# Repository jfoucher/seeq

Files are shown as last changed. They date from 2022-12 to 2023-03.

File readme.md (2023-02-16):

## SEEQ a MIDI and CV/gate sequencer

3D View top

3D View bottom

### What is it?

This project is a simple sequencer I designed and built. I started a project to build an analog synthesizer, but I did not have anything that would be able to output the necessary CV signals, so I decided to build one.

And then I added MIDI input and output to be able to interface with other things.

I designed it around a Raspberry Pi Pico because it is cheap, easy to use and fast.

### Using the sequencer

You have 16 steps, with one key and one LED for each step. Turning the knob in one direction makes the tempo faster, and in the other direction makes it slower.

If you press a key while turning the knob, this changes the pitch of that step.

If you turn the knob while pressing on it, it changes the number of steps in the sequence.

If you turn the knob while pressing on it while having a step switch pressed, it changes the velocity of that (this only has an effect for the MIDI output)

If you press the knob quickly once, it pauses or restarts playback.

If you press the knob twice, you enter recording mode. This then takes MIDI input (over USB or the midi in plug) and assigns the note you play to the current step and advances to the next step.

## Building it

Instructions will come soon

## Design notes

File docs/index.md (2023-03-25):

---
layout: page
title: A simple sequencer with MIDI and CV/gate output
---

[Schematic](https://6px.eu/seeq/fabrication/seeq-schematic.pdf)

[Gerber files](https://6px.eu/seeq/fabrication/seeq-zip.zip)

[Download BOM](https://6px.eu/seeq/fabrication/seeq-bom.csv)

[View BOM](https://6px.eu/seeq/fabrication/seeq-bom.html)

3D View top

3D View bottom

This project is a simple sequencer I designed and built. I started a project to build an analog synthesizer, but I did not have anything that would be able to output the necessary CV signals, so I decided to build one.

And then I added MIDI input and output to be able to interface with other things.

The way it works is fairly simple.

You have 16 steps, with one key and one LED for each step. Turning the knob in one direction makes the tempo faster, and in the other direction makes it slower.

If you press a key while turning the knob, this changes the pitch of that step.

If you turn the knob while pressing on it, it changes the number of steps in the sequence.

If you turn the knob while pressing on it while having a step switch pressed, it changes the velocity of that (this only has an effect for the MIDI output)

If you press the knob quickly once, it pauses or restarts playback.

If you press the knob twice, you enter recording mode. This then takes MIDI input (over USB or the midi in plug) and assigns the note you play to the current step and advances to the next step.

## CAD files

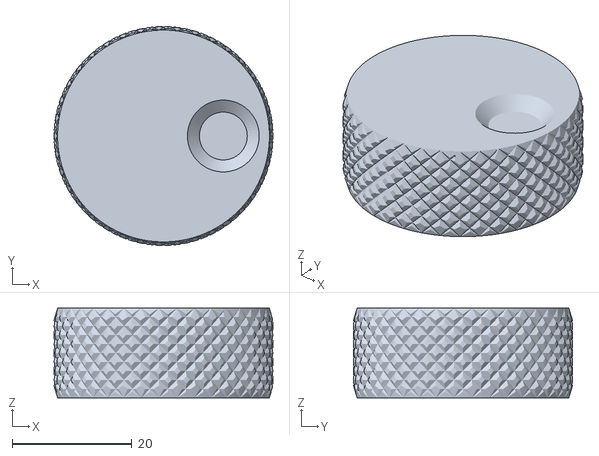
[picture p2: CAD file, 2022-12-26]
case/dist/knob.stl
36.6 x 36.6 x 15.0

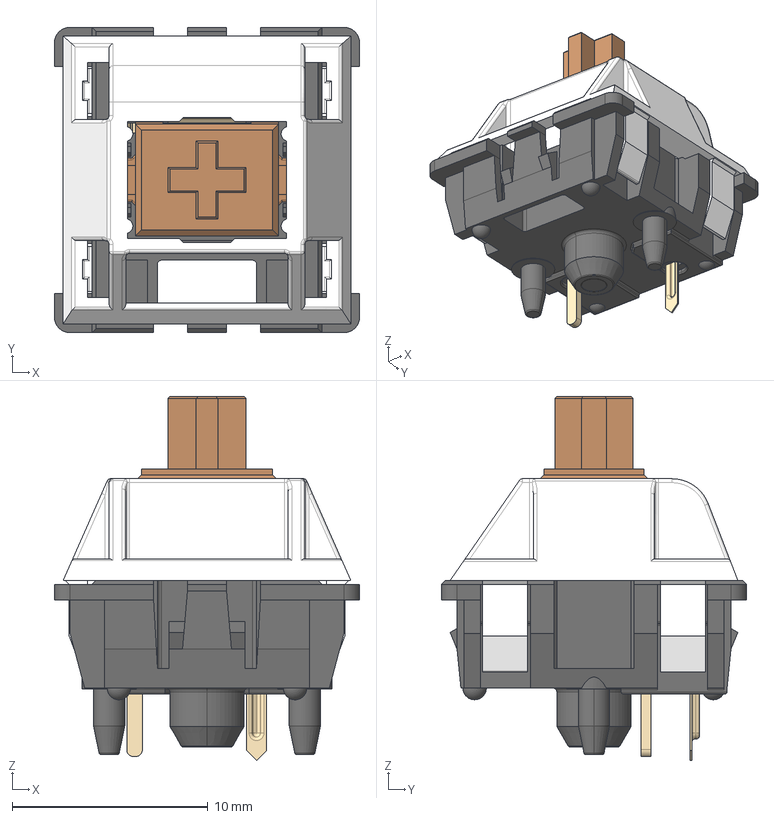
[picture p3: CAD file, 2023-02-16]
hardware/mod/3D/SW_Cherry_MX_PCB.stp
15.6 x 15.6 x 18.6 mm

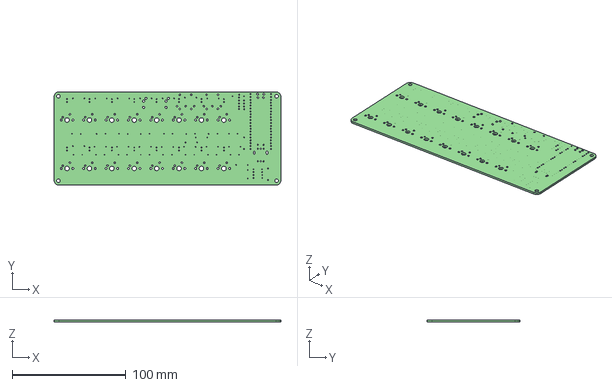
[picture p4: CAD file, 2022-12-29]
hardware/seeq.step
199.5 x 82.0 x 1.60 mm

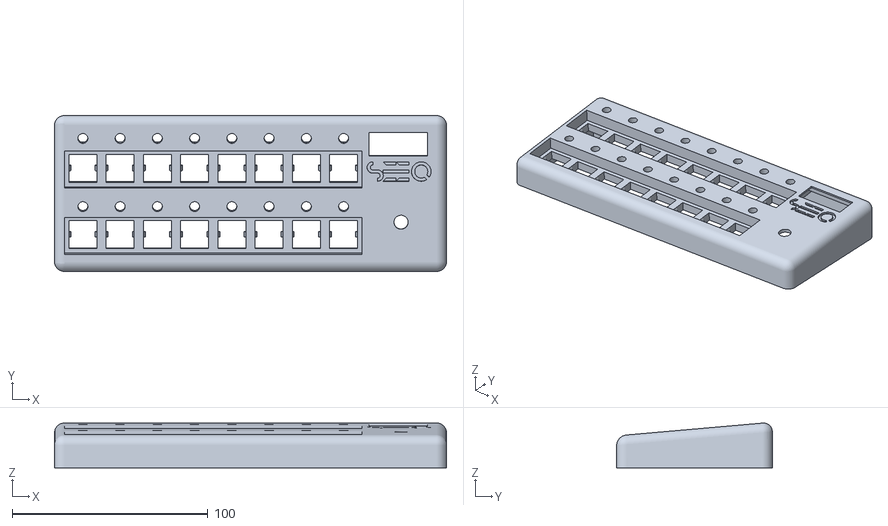
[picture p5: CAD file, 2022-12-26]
case/dist/top.stl
200.5 x 79.7 x 23.0

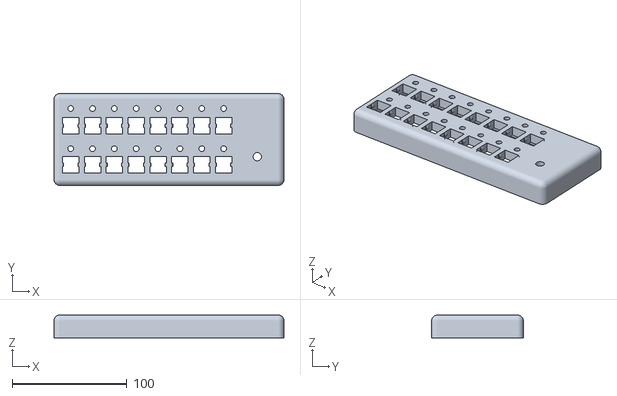
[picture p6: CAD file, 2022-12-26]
case/dist/output.stl
200.5 x 80.0 x 20.0

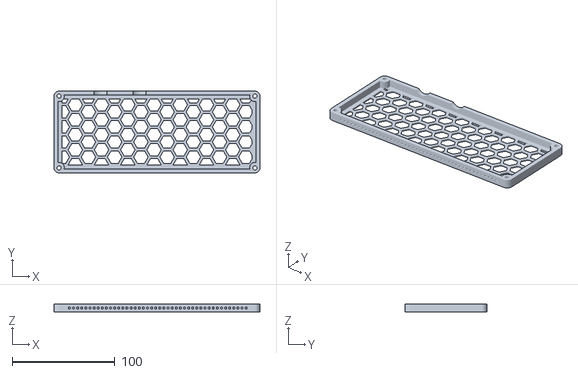
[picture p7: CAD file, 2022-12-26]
case/dist/bottom.stl
200.5 x 79.7 x 8.00

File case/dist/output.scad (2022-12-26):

/*
 * knurledFinishLib.scad
 * 
 * Written by aubenc @ Thingiverse
 *
 * This script is licensed under the Public Domain license.
 *
 * http://www.thingiverse.com/thing:9095
 *
 * Usage:
 *
 *    knurled_cyl( Knurled cylinder height,
 *                 Knurled cylinder outer diameter,
 *                 Knurl polyhedron width,
 *                 Knurl polyhedron height,
 *                 Knurl polyhedron depth,
 *                 Cylinder ends smoothed height,
 *                 Knurled surface smoothing amount );
 */
module knurled_cyl(chg, cod, cwd, csh, cdp, fsh, smt)
{
    cord=(cod+cdp+cdp*smt/100)/2;
    cird=cord-cdp;
    cfn=round(2*cird*PI/cwd);
    clf=360/cfn;
    crn=ceil(chg/csh);

    intersection()
    {
        shape(fsh, cird, cord-cdp*smt/100, cfn*4, chg);

        translate([0,0,-(crn*csh-chg)/2])
          knurled_finish(cord, cird, clf, csh, cfn, crn);
    }
}

module shape(hsh, ird, ord, fn4, hg)
{
        union()
        {
            cylinder(h=hsh, r1=ird, r2=ord, $fn=fn4, center=false);

            translate([0,0,hsh-0.002])
              cylinder(h=hg-2*hsh+0.004, r=ord, $fn=fn4, center=false);

            translate([0,0,hg-hsh])
              cylinder(h=hsh, r1=ord, r2=ird, $fn=fn4, center=false);
        }

}

module knurled_finish(ord, ird, lf, sh, fn, rn)
{
    for(j=[0:rn-1])
    
    {
      h0=sh*j;
      h1=sh*(j+1/2);
      h2=sh*(j+1);
        for(i=[0:fn-1])
        
        {
          lf0=lf*i;
        lf1=lf*(i+1/2);
        lf2=lf*(i+1);
            polyhedron(
                points=[
                     [ 0,0,h0],
                     [ ord*cos(lf0), ord*sin(lf0), h0],
                     [ ird*cos(lf1), ird*sin(lf1), h0],
                     [ ord*cos(lf2), ord*sin(lf2), h0],

                     [ ird*cos(lf0), ird*sin(lf0), h1],
                     [ ord*cos(lf1), ord*sin(lf1), h1],
                     [ ird*cos(lf2), ird*sin(lf2), h1],

                     [ 0,0,h2],
                     [ ord*cos(lf0), ord*sin(lf0), h2],
                     [ ird*cos(lf1), ird*sin(lf1), h2],
                     [ ord*cos(lf2), ord*sin(lf2), h2]
                    ],
                faces=[
                     [0,1,2],[2,3,0],
                     [1,0,4],[4,0,7],[7,8,4],
                     [8,7,9],[10,9,7],
                     [10,7,6],[6,7,0],[3,6,0],
                     [2,1,4],[3,2,6],[10,6,9],[8,9,4],
                     [4,5,2],[2,5,6],[6,5,9],[9,5,4]
                    ],
                convexity=5);
         }
    }
}
$fn = 64;
union()
{
  difference()
  {
    union()
    {
      rotate(a = [5, 0, 0], v = undef)
      {
        union()
        {
          translate(v = [0, -22, -7])
          {
            union()
            {
              translate(v = [-85.72500000000001, 0, 16])
              {
                union()
                {
                  union()
                  {
                    translate(v = [0, 7.95, 2])
                    {
                      cube(size = [17.4, 1.5, 4], center = true);
                    }
                    translate(v = [7.95, 0, 2])
                    {
                      cube(size = [1.5, 17.4, 4], center = true);
                    }
                    hull()
                    {
                      translate(v = [7.2, 0, 1])
                      {
                        rotate(a = [90, 0, 0], v = undef)
                        {
                          cylinder(h = 2.75, r = 1, center = true);
                        }
                      }
                      translate(v = [7.95, 0, 2])
                      {
                        cube(size = [1.5, 2.75, 4], center = true);
                      }
                    }
                  }
                  mirror(v = [0, 1, 0])
                  {
                    mirror(v = [1, 0, 0])
                    {
                      union()
                      {
                        translate(v = [0, 7.95, 2])
                        {
                          cube(size = [17.4, 1.5, 4], center = true);
                        }
                        translate(v = [7.95, 0, 2])
                        {
                          cube(size = [1.5, 17.4, 4], center = true);
                        }
                        hull()
                        {
                          translate(v = [7.2, 0, 1])
                          {
                            rotate(a = [90, 0, 0], v = undef)
                            {
                              cylinder(h = 2.75, r = 1, center = true);
                            }
                          }
                          translate(v = [7.95, 0, 2])
                          {
                            cube(size = [1.5, 2.75, 4], center = true);
                          }
                        }
                      }
                    }
                  }
                }
              }
              translate(v = [-66.67500000000001, 0, 16])
              {
                union()
                {
                  union()
                  {
                    translate(v = [0, 7.95, 2])
                    {
                      cube(size = [17.4, 1.5, 4], center = true);
                    }
                    translate(v = [7.95, 0, 2])
                    {
                      cube(size = [1.5, 17.4, 4], center = true);
                    }
                    hull()
                    {
                      translate(v = [7.2, 0, 1])
                      {
                        rotate(a = [90, 0, 0], v = undef)
                        {
                          cylinder(h = 2.75, r = 1, center = true);
                        }
                      }
                      translate(v = [7.95, 0, 2])
                      {
                        cube(size = [1.5, 2.75, 4], center = true);
                      }
                    }
                  }
                  mirror(v = [0, 1, 0])
                  {
                    mirror(v = [1, 0, 0])
                    {
                      union()
                      {
                        translate(v = [0, 7.95, 2])
                        {
                          cube(size = [17.4, 1.5, 4], center = true);
                        }
                        translate(v = [7.95, 0, 2])
                        {
                          cube(size = [1.5, 17.4, 4], center = true);
                        }
                        hull()
                        {
                          translate(v = [7.2, 0, 1])
                          {
                            rotate(a = [90, 0, 0], v = undef)
                            {
                              cylinder(h = 2.75, r = 1, center = true);
                            }
                          }
                          translate(v = [7.95, 0, 2])
                          {
                            cube(size = [1.5, 2.75, 4], center = true);
                          }
                        }
                      }
                    }
                  }
                }
              }
              translate(v = [-47.62500000000001, 0, 16])
              {
                union()
                {
                  union()
                  {
                    translate(v = [0, 7.95, 2])
                    {
                      cube(size = [17.4, 1.5, 4], center = true);
                    }
                    translate(v = [7.95, 0, 2])
                    {
                      cube(size = [1.5, 17.4, 4], center = true);
                    }
                    hull()
                    {
                      translate(v = [7.2, 0, 1])
                      {
                        rotate(a = [90, 0, 0], v = undef)
                        {
                          cylinder(h = 2.75, r = 1, center = true);
                        }
                      }
                      translate(v = [7.95, 0, 2])
                      {
                        cube(size = [1.5, 2.75, 4], center = true);
                      }
                    }
                  }
                  mirror(v = [0, 1, 0])
                  {
                    mirror(v = [1, 0, 0])
                    {
                      union()
                      {
                        translate(v = [0, 7.95, 2])
                        {
                          cube(size = [17.4, 1.5, 4], center = true);
                        }
                        translate(v = [7.95, 0, 2])
                        {
                          cube(size = [1.5, 17.4, 4], center = true);
                        }
                        hull()
                        {
                          translate(v = [7.2, 0, 1])
                          {
                            rotate(a = [90, 0, 0], v = undef)
                            {
                              cylinder(h = 2.75, r = 1, center = true);
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

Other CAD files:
hardware/seeq.stl

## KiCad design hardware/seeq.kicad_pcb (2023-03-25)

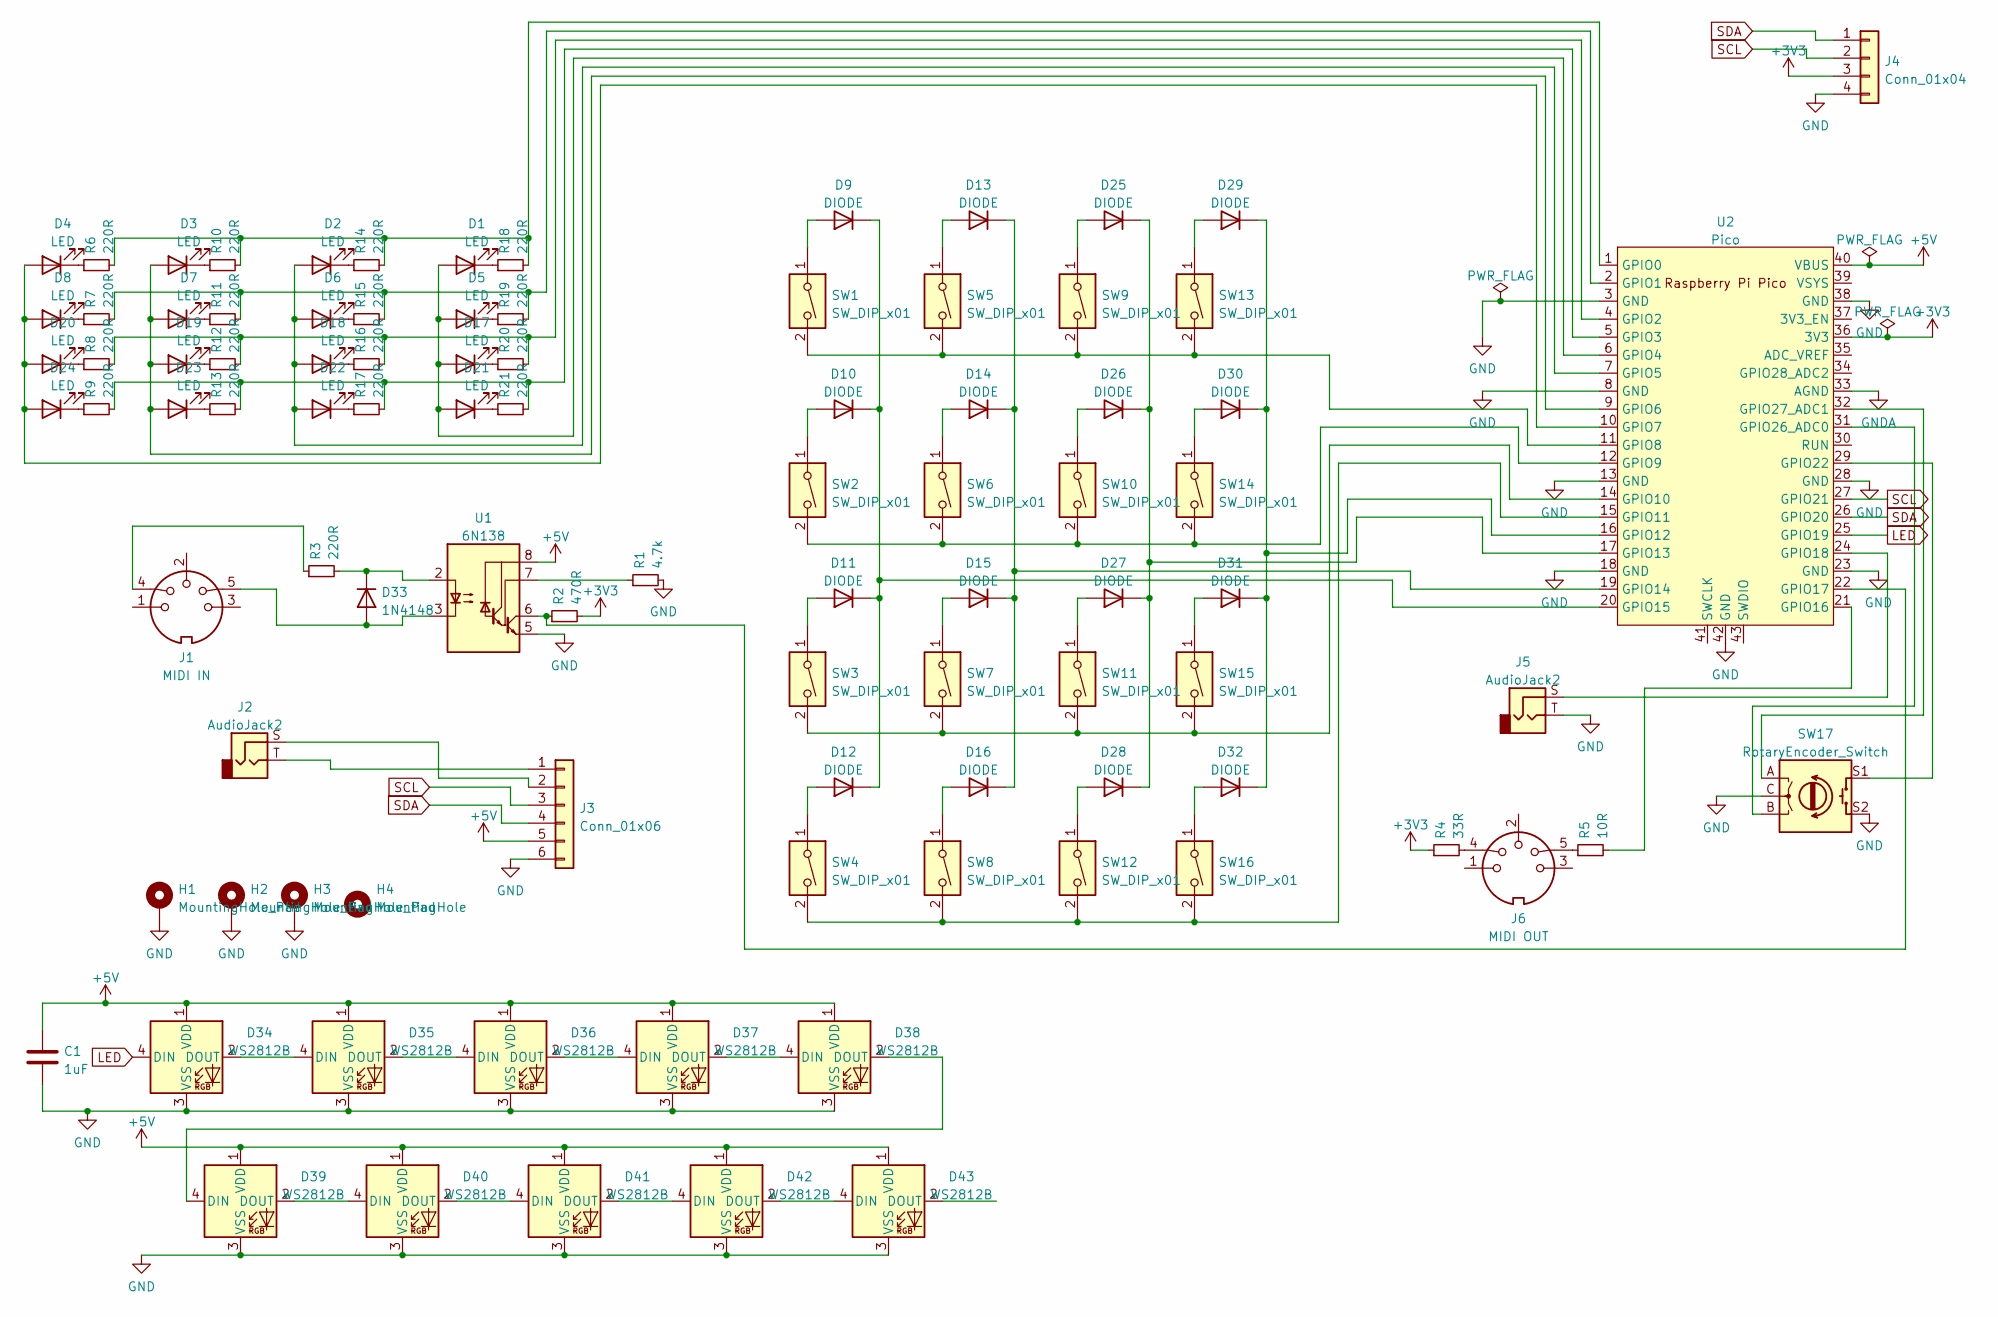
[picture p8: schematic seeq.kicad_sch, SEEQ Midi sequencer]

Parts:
C1: 1uF; C_Disc_D5.0mm_W2.5mm_P5.00mm
D1, D2, D3, D4, D5, D6, D7, D8, D17, D18, D19, D20, D21, D22, D23, D24: LED; LED_D5.0mm
D9, D10, D11, D12, D13, D14, D15, D16, D25, D26, D27, D28, D29, D30, D31, D32: DIODE; D_DO-35_SOD27_P7.62mm_Horizontal
D33: 1N4148; D_DO-35_SOD27_P7.62mm_Horizontal
D34, D35, D36, D37, D38, D39, D40, D41, D42, D43: WS2812B; LED_WS2812B_PLCC4_5.0x5.0mm_P3.2mm
H1, H2, H3: MountingHole_Pad; MountingHole_3.2mm_M3_Pad
H4: MountingHole; MountingHole_3.2mm_M3
J1: MIDI IN; din-5
J2, J5: AudioJack2; TRRS-PJ-320A-no-Fmask
J3: Conn_01x06; PinSocket_1x06_P2.54mm_Vertical
J4: Conn_01x04; PinSocket_1x04_P2.54mm_Vertical
J6: MIDI OUT; din-5
R1: 4.7k; R_Axial_DIN0207_L6.3mm_D2.5mm_P10.16mm_Horizontal
R2: 470R; R_Axial_DIN0207_L6.3mm_D2.5mm_P10.16mm_Horizontal
R3, R6, R7, R8, R9, R10, R11, R12, R13, R14, R15, R16, R17, R18, R19, R20, R21: 220R; R_Axial_DIN0207_L6.3mm_D2.5mm_P10.16mm_Horizontal
R4: 33R; R_Axial_DIN0207_L6.3mm_D2.5mm_P10.16mm_Horizontal
R5: 10R; R_Axial_DIN0207_L6.3mm_D2.5mm_P10.16mm_Horizontal
SW1, SW2, SW3, SW4, SW5, SW6, SW7, SW8, SW9, SW10, SW11, SW12, SW13, SW14, SW15, SW16: SW_DIP_x01; SW_Cherry_MX_PCB_1.00u
SW17: RotaryEncoder_Switch; RotaryEncoder_Alps_EC11E-Switch_Vertical_H20mm
U1: 6N138; DIP-8_W7.62mm
U2: Pico; RPi_Pico_SMD_TH

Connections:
+3V3: J4.3, R2.2, R4.1, U2.36 (3V3)
+5V: C1.1, D34.1 (VDD), D35.1 (VDD), D36.1 (VDD), D37.1 (VDD), D38.1 (VDD), D39.1 (VDD), D40.1 (VDD), D41.1 (VDD), D42.1 (VDD), D43.1 (VDD), J3.5, U1.8 (VCC), U2.40 (VBUS)
GND: C1.2, D34.3 (VSS), D35.3 (VSS), D36.3 (VSS), D37.3 (VSS), D38.3 (VSS), D39.3 (VSS), D40.3 (VSS), D41.3 (VSS), D42.3 (VSS), D43.3 (VSS), H1.1, H2.1, H3.1, J3.6, J4.4, J5.T, R1.2, SW17.C, SW17.S2, U1.5 (GND), U2.3 (GND), U2.8 (GND), U2.13 (GND), U2.18 (GND), U2.23 (GND), U2.28 (GND), U2.38 (GND), U2.42 (GND)
GNDA: U2.33 (AGND)
LED: D34.4 (DIN), U2.25 (GPIO19)
unnamed: D1.1 (K), R18.1
unnamed: D1.2 (A), D5.2 (A), D17.2 (A), D21.2 (A), U2.6 (GPIO4)
unnamed: D2.1 (K), R14.1
unnamed: D3.1 (K), R10.1
unnamed: D4.1 (K), R6.1
unnamed: D5.1 (K), R19.1
unnamed: D6.1 (K), R15.1
unnamed: D7.1 (K), R11.1
unnamed: D8.1 (K), R7.1
unnamed: D9.2 (A), SW1.1
unnamed: D9.1 (K), D10.1 (K), D11.1 (K), D12.1 (K), U2.20 (GPIO15)
unnamed: D10.2 (A), SW2.1
unnamed: D11.2 (A), SW3.1
unnamed: D12.2 (A), SW4.1
unnamed: D13.1 (K), D14.1 (K), D15.1 (K), D16.1 (K), U2.19 (GPIO14)
unnamed: D13.2 (A), SW5.1
unnamed: D14.2 (A), SW6.1
unnamed: D15.2 (A), SW7.1
unnamed: D16.2 (A), SW8.1
unnamed: D17.1 (K), R20.1
unnamed: D18.1 (K), R16.1
unnamed: D2.2 (A), D6.2 (A), D18.2 (A), D22.2 (A), U2.7 (GPIO5)
unnamed: D19.1 (K), R12.1
unnamed: D3.2 (A), D7.2 (A), D19.2 (A), D23.2 (A), U2.9 (GPIO6)
unnamed: D20.1 (K), R8.1
unnamed: D4.2 (A), D8.2 (A), D20.2 (A), D24.2 (A), U2.10 (GPIO7)
unnamed: D21.1 (K), R21.1
unnamed: D22.1 (K), R17.1
unnamed: D23.1 (K), R13.1
unnamed: D24.1 (K), R9.1
unnamed: D25.1 (K), D26.1 (K), D27.1 (K), D28.1 (K), U2.17 (GPIO13)
unnamed: D25.2 (A), SW9.1
unnamed: D26.2 (A), SW10.1
unnamed: D27.2 (A), SW11.1
unnamed: D28.2 (A), SW12.1
unnamed: D29.1 (K), D30.1 (K), D31.1 (K), D32.1 (K), U2.16 (GPIO12)
unnamed: D29.2 (A), SW13.1
unnamed: D30.2 (A), SW14.1
unnamed: D31.2 (A), SW15.1
unnamed: D32.2 (A), SW16.1
unnamed: D33.1 (K), R3.2, U1.2 (C1)
unnamed: D33.2 (A), J1.5, U1.3 (C2)
unnamed: D34.2 (DOUT), D35.4 (DIN)
unnamed: D35.2 (DOUT), D36.4 (DIN)
unnamed: D36.2 (DOUT), D37.4 (DIN)
unnamed: D37.2 (DOUT), D38.4 (DIN)
unnamed: D38.2 (DOUT), D39.4 (DIN)
unnamed: D39.2 (DOUT), D40.4 (DIN)
unnamed: D40.2 (DOUT), D41.4 (DIN)
unnamed: D41.2 (DOUT), D42.4 (DIN)
unnamed: D42.2 (DOUT), D43.4 (DIN)
unnamed: J1.4, R3.1
unnamed: J2.S, J3.2
unnamed: J2.T, J3.1
unnamed: J5.S, U2.24 (GPIO18)
unnamed: J6.4, R4.2
unnamed: J6.5, R5.1
unnamed: R1.1, U1.7 (VO1)
unnamed: R2.1, U1.6 (VO2), U2.22 (GPIO17)
unnamed: R5.2, U2.21 (GPIO16)
unnamed: R6.2, R10.2, R14.2, R18.2, U2.1 (GPIO0)
unnamed: R7.2, R11.2, R15.2, R19.2, U2.2 (GPIO1)
unnamed: R8.2, R12.2, R16.2, R20.2, U2.4 (GPIO2)
unnamed: R9.2, R13.2, R17.2, R21.2, U2.5 (GPIO3)
unnamed: SW1.2, SW5.2, SW9.2, SW13.2, U2.11 (GPIO8)
unnamed: SW2.2, SW6.2, SW10.2, SW14.2, U2.12 (GPIO9)
unnamed: SW3.2, SW7.2, SW11.2, SW15.2, U2.14 (GPIO10)
unnamed: SW4.2, SW8.2, SW12.2, SW16.2, U2.15 (GPIO11)
unnamed: SW17.A, U2.32 (GPIO27_ADC1)
unnamed: SW17.B, U2.31 (GPIO26_ADC0)
unnamed: SW17.S1, U2.29 (GPIO22)
SCL: J3.3, J4.2, U2.27 (GPIO21)
SDA: J3.4, J4.1, U2.26 (GPIO20)

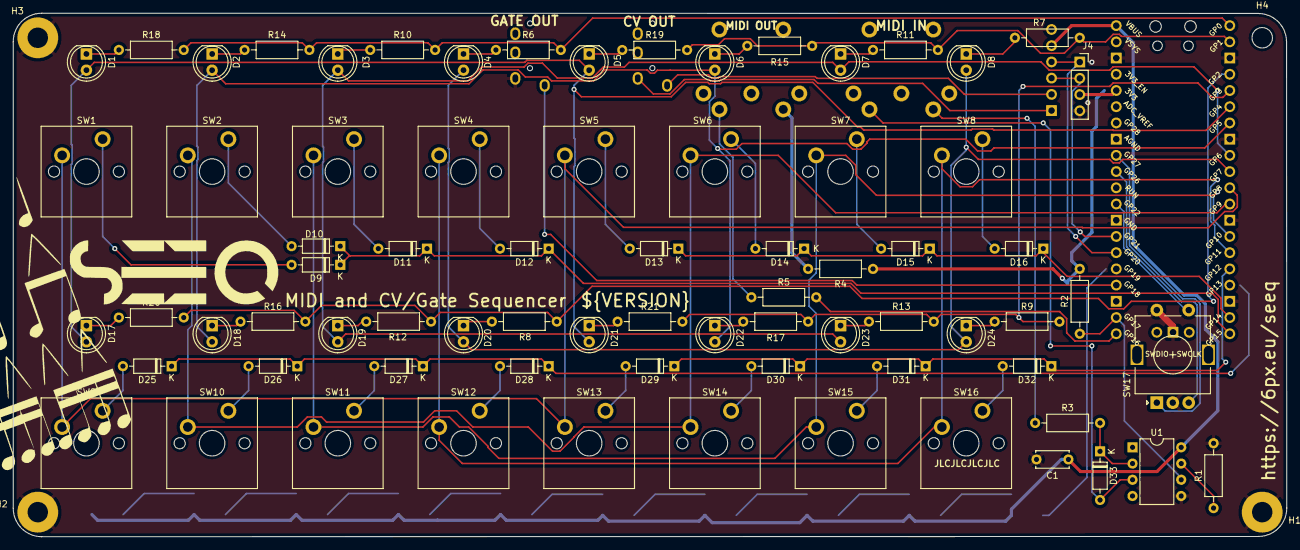
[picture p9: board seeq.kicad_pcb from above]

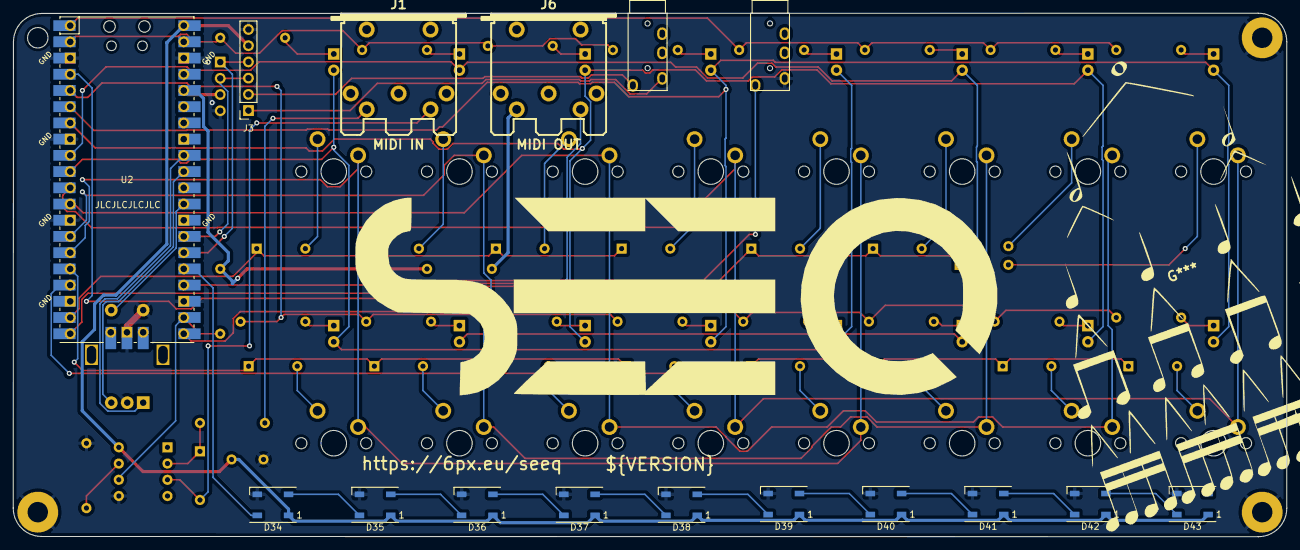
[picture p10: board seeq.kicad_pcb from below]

Board: 2 copper layers, 199.5 x 82.0 mm, 94 parts (16 on the bottom side), 77 nets.

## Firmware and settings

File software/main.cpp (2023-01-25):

/* 
 * The MIT License (MIT)
 *
 * Copyright (c) 2022 Jonathan Foucher - Six Pixels
 *
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
 */

#include <stdlib.h>
#include <stdio.h>
#include <string.h>
#include <stdarg.h>

#include "pico/stdlib.h"
#include "pico/time.h"
#include "pico/sync.h"
#include "hardware/clocks.h"
#include "hardware/vreg.h"
#include "hardware/flash.h"
#include "pico/multicore.h"
#include "pico/util/queue.h"
#include "lib/encoder/encoder.hpp"
#include "lib/OLED/OLED.h"
#include "lib/OLED/font/Cherry_Cream_Soda_Regular_16.h"
#include "lib/OLED/font/Dialog_bold_16.h"

#include "pico/binary_info.h"


#include "lib/picoLED/PicoLed.hpp"

#include "bsp/board.h"
#include "tusb.h"

#include "lib/midi/midi.h"
#include "lib/keypad/keypad.h"

#include "lib/midi/midi.c"
#include "lib/mcp4725/mcp4725.h"
#include "lib/mcp4725/mcp4725.c"
#include "lib/encoder_button/encoder_button.h"
#include "lib/encoder_button/encoder_button.c"
#include "lib/midi_uart_lib/midi_uart_lib.h"

#define MIDI_UART_NUM 1
#define CABLE_NUM 0 // MIDI jack associated with USB endpoint
#define CHANNEL 0 // 0 for channel 1
#define ENCODER_PIN_A 27
#define ENCODER_PIN_B 26

#define FLASH_TARGET_OFFSET (512 * 1024)

 
const uint8_t *flash_target_contents = (const uint8_t *) (XIP_BASE + FLASH_TARGET_OFFSET);

const uint MIDI_UART_TX_GPIO = 16;
const uint MIDI_UART_RX_GPIO = 17;

static void *midi_uart_instance;

void println(const char * format, ... );
void print(const char * format, ... );

void __time_critical_func(core1_func)();
void save_data_task(void);
static semaphore_t video_initted;

uint8_t midi_message[4];
int midi_message_index = 0;

queue_t queue;
queue_t note_queue;
queue_t cv_note_queue;

uint8_t sequence[16] = {74,78,81,86,90,93,98,102,57,61,66,69,73,78,81,85};
uint8_t active[16] = {true, true, true, true,true, true, true, true,true, true, true, true,true, true, true, true};
uint8_t velocity[16] = {127, 127, 127, 127,127, 127, 127, 127,127, 127, 127, 127,127, 127, 127, 127};
int8_t pressed_key = -1;
uint8_t first_step = 0;
uint8_t last_step = 15;
uint8_t new_last_step = 15;
uint8_t current_led = 0;
uint8_t previous_led = 20;
uint8_t play_step = 0;
uint8_t led_row_pins[4] = {0,1,2,3};
uint8_t led_col_pins[4] = {4,5,6,7};

uint16_t tempo = 120;
uint16_t old_tempo = 0;


int note_display = -1;
int old_note_display = 0;
uint16_t note_message = 0;
uint8_t cv_note_message = 0;
uint8_t new_cv_note = 0;

absolute_time_t t;
absolute_time_t last_play_time;
absolute_time_t last_off_time;
absolute_time_t last_keypad_time;
absolute_time_t last_save_time;
absolute_time_t last_manual_save_time;
absolute_time_t last_manual_play_time;
absolute_time_t last_tapped_time;
bool playing = true;
bool recording = false;
bool handled_key_and_encoder_pressed = false;
bool changed_enc_count_on_press = false;

struct SeeqData {
  uint16_t header;
  uint16_t tempo;
  uint8_t first_step;
  uint8_t last_step;
  uint8_t sequence[16];
  uint8_t active[16];
  uint8_t velocity[16];
};

// Keypad pins

uint8_t row_pins[] = {8,9,10,11};
uint8_t col_pins[] = {15,14,13,12};



void init_leds() {
    for(int i = 0; i<4;i++) {
        uint8_t p = led_row_pins[i];

        gpio_init(p);
        gpio_set_dir(p, GPIO_OUT);
        gpio_put(p, 1);
    }
    for(int i = 0; i<4;i++) {
        uint8_t p = led_col_pins[i];

        gpio_init(p);
        gpio_set_dir(p, GPIO_OUT);
        gpio_put(p, 0);
    }
}

int cv_notes[] = {0, 68, 136, 204, 273, 341, 409, 477, 546, 614, 682, 750, 819, 887, 955, 1024, 1092, 1160, 1228, 1297, 1365, 1433, 1501, 1570, 1638, 1706, 1774, 1843, 1911, 1979, 2048, 2116, 2184, 2252, 2321, 2389, 2457, 2525, 2594, 2662, 2730, 2798, 2867, 2935, 3003, 3072, 3140, 3208, 3276, 3345, 3413, 3481, 3549, 3618, 3686, 3754, 3822, 3891, 3959, 4027, 4096}; 

int midi_to_cv(uint8_t midi_note) {
  // Only return something for octaves from 0 to 5
  if (midi_note < 36 || midi_note > 96 ) {
    return 0;
  }

  return cv_notes[midi_note - 36];
}


SeeqData seeqData;

bool saveData() {
    seeqData.tempo = tempo;
    seeqData.header = 0x55AA;
    for (int i = 0; i< 16; i++) {
      seeqData.sequence[i] = sequence[i];
      seeqData.active[i] = active[i];
      seeqData.velocity[i] = velocity[i];
    }
    seeqData.last_step = last_step;
    seeqData.first_step = first_step;

    uint8_t* dataAsBytes = (uint8_t*) &seeqData;
    int dataSize = sizeof(seeqData);
    
    int writeSize = (dataSize / FLASH_PAGE_SIZE) + 1; // how many flash pages we're gonna need to write
    int sectorCount = ((writeSize * FLASH_PAGE_SIZE) / FLASH_SECTOR_SIZE) + 1; // how many flash sectors we're gonna need to erase
    uint32_t interrupts = save_and_disable_interrupts();
    flash_range_erase(FLASH_TARGET_OFFSET, FLASH_SECTOR_SIZE * sectorCount);
    flash_range_program(FLASH_TARGET_OFFSET, dataAsBytes, FLASH_PAGE_SIZE * writeSize);
    restore_interrupts(interrupts);

    for (int i = 0; i < dataSize; ++i) {
        if (dataAsBytes[i] != flash_target_contents[i])
            return false;
    }
    
    return true;
}

void readData() {
    memcpy(&seeqData, flash_target_contents, sizeof(seeqData));
    if (seeqData.header != 0x55AA) {
      return;
    }
    if (seeqData.tempo > 0 && seeqData.tempo <= 5000) {
      tempo = seeqData.tempo;
    }
    if (seeqData.last_step >= 0 && seeqData.last_step <= 15) {
      last_step = (uint8_t)seeqData.last_step;
      new_last_step = last_step;
    }

    if (seeqData.first_step >= 0 && seeqData.first_step <= 15) {
      first_step = (uint8_t)seeqData.first_step;
    }

    for (int i=0; i < 16; i++) {
      if (seeqData.sequence[i] <= 0x7F) {
        sequence[i] = seeqData.sequence[i];
      }
      if (seeqData.active[i] <= 0x7F) {
        active[i] = (bool)seeqData.active[i];
      }

      if (seeqData.velocity[i] <= 0x7F) {
        velocity[i] = (uint8_t)seeqData.velocity[i];
      }
    }
}

void led_display(uint8_t led) {
    if (led == previous_led) {
        return ;
    }
    previous_led = led;
    //turn off all leds
    for(int i = 0; i<4;i++) {
        uint8_t p = led_row_pins[i];
        gpio_put(p, 1);
    }
    for(int i = 0; i<4;i++) {
        uint8_t p = led_col_pins[i];
        gpio_put(p, 0);
    }
    if (led < 16 && led >= 0) {
        uint8_t row = led / 4;
        uint8_t col = led % 4;
        gpio_put(led_row_pins[row], 0);
        gpio_put(led_col_pins[col], 1);
    }
}

const char * notes[] = {
    "C", "C#", "D", "D#", "E", "F", "F#", "G", "G#", "A", "A#", "B"
};


void note_text(char * note_str, uint8_t midi_note) {
  int n = ((int)midi_note) - 24;
  int octave = n / 12;
  if (n < 0) {
    octave = -octave;
  }
  const char * note = notes[midi_note%12];

  sprintf(note_str, "%s%i", note, octave);
}

void __time_critical_func(core1_func)() {    
      // SCL, SDA, Width, Height, Frequency, I2C Port
    OLED oled(21, 20, 128, 32, 300000, false, i2c0);

    // Draw two circles
    oled.drawFilledCircle(100, 4, 4);

    // Print custom font string
    oled.setFont(&Dialog_bold_16);
    uint8_t string2[] = "SEEQ";
    oled.print(60, 5, string2);
    oled.drawFilledRectangle(120, 10, 8, 24);
    // Draw a line
    oled.drawFastHLine(0, 31, 128);
    oled.drawFastHLine(0, 0, 128);
    oled.show();
    
    sleep_ms(500);

    sem_release(&video_initted);
    // Turn scroll ON
    // oled.setScrollDir(true);
    // oled.isScroll(true);
    while (true) {
        tight_loop_contents();
        while (queue_try_remove(&cv_note_queue, &new_cv_note)){
            mcp4725_set(i2c0, MCP4725_ADDR0, midi_to_cv(new_cv_note));
        }

        uint16_t new_tempo = old_tempo;
        while (queue_try_remove(&queue, &new_tempo)){}
        int new_note_display = old_note_display;

        while (queue_try_remove(&note_queue, &new_note_display)){}

        bool clear = old_note_display != new_note_display || old_tempo != new_tempo;

        if (clear) {
          oled.clear();

          char intStr[4];
          sprintf(intStr, "%d",  new_tempo);
          oled.print(0, 0, (uint8_t *)intStr);
          old_tempo = new_tempo;

          char str[4];
          uint8_t note = (new_note_display & 0xFF);
          if (note >= 0 && note <= 0x7F) {
            note_text(str, note);
            //println("note text %s", str);
            
          } else {
            sprintf(str, "%s",  "  - ");
          }

          oled.print(64, 0, (uint8_t *)str);
          old_note_display = new_note_display;
          uint8_t vh = (uint8_t)(new_note_display >> 8) / 4;
          // draw velocity rectangle
          uint8_t y_start = 32 - vh;
          oled.drawFilledRectangle(120, y_start, 8, vh);
        
          oled.show();
        }
    }
}

void print(const char * format, ... ) {
    char text[64];
    va_list arguments;
    va_start(arguments, format);
    // https://mylifeforthecode.github.io/creating-a-custom-printf-function-in-c/
    vsprintf(text, format, arguments);
    va_end(arguments);
    tud_cdc_write(text, strlen(text));
    tud_cdc_write_flush();
}

void println(const char * format, ... ) {
    char text[64];
    va_list arguments;
    va_start(arguments, format);
    // https://mylifeforthecode.github.io/creating-a-custom-printf-function-in-c/
    vsprintf(text, format, arguments);
    va_end(arguments);
    strcat(text, "\n");
    tud_cdc_write(text, strlen(text));
    tud_cdc_write_flush();
}

int note_to_stop = -1;
void rotaryChangedCallback(encoder::Encoder * enc)
{
  int x = enc->count();
  if (pressed_key >= 0 && pressed) {
    // A key is pressed and the rotary encoder as well, 
    // change the velocity
    if (x < 0) {
        x = 0;
        enc->set_count(x);
    }
    if (x > 127) {
        x = 127;
        enc->set_count(x);
    }
    velocity[pressed_key] = x;
  } else if (pressed_key >= 0) {
    // A key is pressed, so change corresponding note
    if (x < 0) {
        x = 0;
        enc->set_count(x);
    }
    if (x > 127) {
        x = 127;
        enc->set_count(x);
    }
    note_off(sequence[pressed_key]);
    sequence[pressed_key] = x;
    if (!playing) {
      note_on(sequence[pressed_key], velocity[pressed_key]);
      cv_note_message = sequence[pressed_key];
      queue_try_add(&cv_note_queue, &cv_note_message);
      //sleep_ms(100);
      note_to_stop = sequence[pressed_key];
      last_manual_play_time = get_absolute_time();
    }
  } else if (pressed) {
    // Encoder is pressed, change last step
    if (x < 0) {
        x = 0;
        enc->set_count(x);
    }
    if (x > 15) {
        x = 15;
        enc->set_count(x);
    }
    new_last_step = x;
  } else if (recording && !playing) {
    if (x < 0) {
        x = 0;
        enc->set_count(x);
    }
    if (x > last_step) {
        x = last_step;
        enc->set_count(x);
    }
    play_step = (uint16_t)x;
    current_led = x;
    note_message = sequence[play_step] | velocity[play_step] << 8;
    queue_try_add(&note_queue, &note_message);
  } else {
    if (x < 1) {
        x = 1;
        enc->set_count(x);
    }
    if (x > 5000) {
        x = 5000;
        enc->set_count(x);
    }
    tempo = (uint16_t)x;

    queue_try_add(&queue, &tempo);
  }
}


void midi_task(void);
void cdc_task(void);
void keypad_task(void);
void led_task(void);

encoder::Encoder enc(pio0, 0, {ENCODER_PIN_A, ENCODER_PIN_B});
auto ledStrip = PicoLed::addLeds<PicoLed::WS2812B>(pio0, 1, 23, 1, PicoLed::FORMAT_GRB);
PicoLed::Color led_color = PicoLed::RGB(0, 80, 0);
PicoLed::Color old_led_color = PicoLed::RGB(0, 80, 0);


/*------------- MAIN -------------*/
int main(void)
{
  #ifdef OVERCLOCK
    vreg_set_voltage(VREG_VOLTAGE_1_15);
    set_sys_clock_khz(260000, true);
  #endif
  stdio_init_all();


  board_init();

  tusb_init();


  init_leds();

  init_matrix(4, 4, row_pins, col_pins);

  midi_uart_instance = midi_uart_configure(MIDI_UART_NUM, MIDI_UART_TX_GPIO, MIDI_UART_RX_GPIO);

  pressed = false;

  //Init encoder button
  encoder_init(22);



  enc.init();
  enc.set_count(tempo);
  enc.setCallback(rotaryChangedCallback);
  playing = true;



  // create a semaphore to be posted when video init is complete
  sem_init(&video_initted, 0, 1);

  // launch all the video on core 1, so it isn't affected by USB handling on core 0
  multicore_launch_core1(core1_func);
  // wait for initialization of video to be complete
  sem_acquire_blocking(&video_initted);
  // restore saved data
  readData();

  queue_init(&queue, sizeof(tempo), 32);
  queue_try_add(&queue, &tempo);

  queue_init(&note_queue, sizeof(uint16_t), 32);
  note_message = note_display;
  queue_try_add(&note_queue, &note_message);

  queue_init(&cv_note_queue, sizeof(uint8_t), 32);
  queue_try_add(&cv_note_queue, &cv_note_message);

  last_play_time = get_absolute_time();
  last_off_time = get_absolute_time();
  last_keypad_time = get_absolute_time();
  last_save_time = get_absolute_time();
  last_manual_save_time = get_absolute_time();
  last_manual_play_time = get_absolute_time();
  last_tapped_time = get_absolute_time();
  ledStrip.fill(led_color);
  ledStrip.show();

  while (1)
  {
    tud_task(); // tinyusb device task
    keypad_task();
    midi_task();
    cdc_task();
    save_data_task();
    led_task();
  }


  return 0;
}

//--------------------------------------------------------------------+
// MIDI Task
//--------------------------------------------------------------------+

void midi_task(void)
{
  t = get_absolute_time();

  int64_t delta = absolute_time_diff_us(last_play_time, t);
  int64_t delta_off = absolute_time_diff_us(last_off_time, t);

  led_display(current_led);

  if (playing && delta > 60000000 / tempo) {
    last_play_time = t;

    if (active[play_step]) {
      note_on(sequence[play_step], velocity[play_step]);
      cv_note_message = sequence[play_step];
      queue_try_add(&cv_note_queue, &cv_note_message);
      
      current_led = play_step;
      if (pressed_key < 0) {
        note_display = sequence[play_step];
        //println("showing note %i", note);
        note_message = note_display | (velocity[play_step] << 8);
        queue_try_add(&note_queue, &note_message);
      }
    } else {
      current_led = -1;
      if (pressed_key < 0) {
        note_display = -1;
        //println("showing note %i", note);
        queue_try_add(&note_queue, &note_display);
      }
    }

    play_step++;
    if (play_step > last_step) {
        play_step = first_step;
    }
  } else if (playing && delta > 30000000 / tempo and delta_off > 60000000 / tempo) {
    last_off_time = t;
    uint8_t ps = play_step - 1;
    if (ps == 0xFF) {
      ps = last_step;
    }
    note_off(sequence[ps]);

  } else if (!playing && note_to_stop >=0 && absolute_time_diff_us(last_manual_play_time, get_absolute_time()) > 100000) {
    note_off(note_to_stop);
    
    note_to_stop = -1;
  }

  

  if (pressed && !changed_enc_count_on_press && pressed_key < 0) {
    println("preprare to change new last step");
    new_last_step = last_step;
    enc.set_count(last_step);
    changed_enc_count_on_press = true;
  } else if (!pressed && changed_enc_count_on_press  && pressed_key < 0) {
    println("done changing  new last step");
    enc.set_count(tempo);
    changed_enc_count_on_press = false;
  }

  if (pressed && pressed_key >= 0 && !handled_key_and_encoder_pressed) {
    // Key and encoder pressed at the same time, will change velocity
    // set encoder to pressed key velocity
    enc.set_count(velocity[pressed_key]);
    handled_key_and_encoder_pressed = true;
  }

  if (!pressed && handled_key_and_encoder_pressed) {
    enc.set_count(sequence[pressed_key]);
    handled_key_and_encoder_pressed = false;
  }
  if (pressed_key < 0 && handled_key_and_encoder_pressed) {
    enc.set_count(tempo);
    handled_key_and_encoder_pressed = false;
  }

  if (!pressed && new_last_step != last_step && play_step == 0) {
    println("setting last step to new last step %d %d", last_step, new_last_step);
    note_off(sequence[last_step]);
    last_step = new_last_step;
  }

  if (pressed && pressed_key < 0) {
    led_display(new_last_step);
  }

  if (pressed && absolute_time_diff_us(pressed_at, get_absolute_time()) > 2000000 && last_step == new_last_step && absolute_time_diff_us(last_manual_save_time, get_absolute_time()) > 1000000) {
    // Long press without rotation, save data
    last_manual_save_time = get_absolute_time();
    saveData();
  }

  // Button tapped event
  if (!pressed 
    && to_ms_since_boot(released_at) > to_ms_since_boot(pressed_at) 
    && absolute_time_diff_us(pressed_at, released_at) < 500000
    && absolute_time_diff_us(last_tapped_time, released_at) > 500000
  ) {
    pressed_at = t;
    last_tapped_time = t;
    if (pressed_key < 0) {
      // If no key is pressed change state
      println("change state");
      playing = !playing;
      recording = false;
      if (!playing) {
        note_message = sequence[play_step] | (velocity[play_step] << 8);
        queue_try_add(&note_queue, &note_message);
        for (int j = 0; j < 16; j++) {
          note_off(sequence[j]);
        }
        
        led_color = PicoLed::RGB(80, 0, 0);
      } else {
        led_color = PicoLed::RGB(0, 80, 0);
      }
    } else {
      // If a key is pressed, toggle note
      active[pressed_key] = !active[pressed_key];
    }
  }
  // Second button tapped event
  if (!pressed 
    && to_ms_since_boot(released_at) > to_ms_since_boot(pressed_at) 
    && absolute_time_diff_us(pressed_at, released_at) < 500000
    && absolute_time_diff_us(last_tapped_time, released_at) < 500000
  ) {
    println("recording state");
    pressed_at = t;
    last_tapped_time = t;
    playing = false;
    recording = true;
    play_step = 0;
    current_led = 0;
    enc.set_count(0);
    led_color = PicoLed::RGB(0, 0, 80);
    note_message = sequence[play_step] | velocity[play_step] << 8;
    queue_try_add(&note_queue, &note_message);
  }

  uint8_t rx[48];
  uint8_t nread;

  while((nread = midi_uart_poll_rx_buffer(midi_uart_instance, rx, sizeof(rx))) > 0){
    for (int b = 0; b < nread; b++) {
      if (rx[b] == 0xFE) {
        midi_message_index = 0;
      } else {
        midi_message[midi_message_index] = rx[b];
        midi_message_index++;
      }
    }
    
  }

  if (midi_message_index >= 3) {
    midi_message_index = 0;
    if (recording && midi_message[0] == 0x90 && midi_message[2] > 0) {
      // Note on
        sequence[play_step] = midi_message[1];
        velocity[play_step] = midi_message[2];
        
        
        note_message = sequence[play_step] | velocity[play_step] << 8;
        cv_note_message = sequence[play_step];
        queue_try_add(&note_queue, &note_message);
        queue_try_add(&cv_note_queue, &cv_note_message);
        note_on(sequence[play_step], velocity[play_step]);
        note_off(sequence[play_step]);

        play_step++;
        if (play_step > last_step) {
            play_step = first_step;
        }
        current_led = play_step;
    }
  }
  


  // The MIDI interface always creates input and output port/jack descriptors
  // regardless of these being used or not. Therefore incoming traffic should be read
  // (possibly just discarded) to avoid the sender blocking in IO
  uint8_t packet[4];
  while (tud_midi_available()) {
    tud_midi_packet_read(packet);
    if (recording) {
      //println("USB MIDI %02X %02X %02X %02X", packet[0], packet[1], packet [2], packet [3]);
      if (packet[0] == 0x09 && packet[1] == 0x90) {
        // Note on message
        sequence[play_step] = packet[2];
        velocity[play_step] = packet[3];
        
        play_step++;
        if (play_step > last_step) {
            play_step = first_step;
        }
        note_message = sequence[play_step] | velocity[play_step] << 8;
        queue_try_add(&note_queue, &note_message);
        current_led = play_step;
      }
    }
    
  }
}

bool removed_note = true;


void keypad_task() {
  if (pressed_key >= 0) {
    led_display((uint8_t)pressed_key);
  }
  int64_t delta = absolute_time_diff_us(last_play_time, get_absolute_time());
  if (delta > 10000) {
    int result = scan_matrix();
    if (result >= 0) {
      pressed_key = (int8_t)result;
      if (pressed) {
        enc.set_count(velocity[pressed_key]);
      } else {
        enc.set_count(sequence[pressed_key]);
      }
      
      note_message = sequence[pressed_key] | (velocity[pressed_key] << 8);
      if (note_message != note_display) {
        queue_try_add(&note_queue, &note_message);
        note_display = note_message;
        removed_note = false;
      }
      
    } else {
      pressed_key = -1;
      int pk = pressed_key;
      if (pk != note_display && !removed_note) {
        queue_try_add(&note_queue, &pk);
        note_display = pk;
        removed_note = true;
      }
      uint8_t ls = last_step;
      if (new_last_step != ls) {
        ls = new_last_step;
      }
      enc.set_count(playing ? (pressed ? ls : tempo) : play_step);
    }
  }
}

void save_data_task() {
  int64_t delta = absolute_time_diff_us(last_save_time, get_absolute_time());
  int64_t delta2 = absolute_time_diff_us(last_play_time, t);
  // Autosave every minute

  if (delta > 60000000 && delta2 < 1000) {
    saveData();
    last_save_time = get_absolute_time();
    
  }
}



void led_task() {
  if (old_led_color.blue != led_color.blue || old_led_color.red != led_color.red || old_led_color.green != led_color.green ) {
    ledStrip.fill(led_color);
    ledStrip.show();
    old_led_color = led_color;
  }
}


//--------------------------------------------------------------------+
// Device callbacks
//--------------------------------------------------------------------+

// Invoked when device is mounted
void tud_mount_cb(void)
{

}

// Invoked when device is unmounted
void tud_umount_cb(void)
{

}

// Invoked when usb bus is suspended
// remote_wakeup_en : if host allow us  to perform remote wakeup
// Within 7ms, device must draw an average of current less than 2.5 mA from bus
void tud_suspend_cb(bool remote_wakeup_en)
{
  (void) remote_wakeup_en;

}
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

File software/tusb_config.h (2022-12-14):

/*
 * The MIT License (MIT)
 *
 * Copyright (c) 2022 Jonathan Foucher - Six Pixels
 *
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
 */

#ifndef _TUSB_CONFIG_H_
#define _TUSB_CONFIG_H_

#ifdef __cplusplus
 extern "C" {
#endif

//--------------------------------------------------------------------
// COMMON CONFIGURATION
//--------------------------------------------------------------------

// defined by board.mk
#ifndef CFG_TUSB_MCU
  #error CFG_TUSB_MCU must be defined
#endif

// RHPort number used for device can be defined by board.mk, default to port 0
#ifndef BOARD_DEVICE_RHPORT_NUM
  #define BOARD_DEVICE_RHPORT_NUM     0
#endif

// RHPort max operational speed can defined by board.mk
// Default to Highspeed for MCU with internal HighSpeed PHY (can be port specific), otherwise FullSpeed
#ifndef BOARD_DEVICE_RHPORT_SPEED
  #if (CFG_TUSB_MCU == OPT_MCU_LPC18XX || CFG_TUSB_MCU == OPT_MCU_LPC43XX || CFG_TUSB_MCU == OPT_MCU_MIMXRT10XX || \
       CFG_TUSB_MCU == OPT_MCU_NUC505  || CFG_TUSB_MCU == OPT_MCU_CXD56)
    #define BOARD_DEVICE_RHPORT_SPEED   OPT_MODE_HIGH_SPEED
  #else
    #define BOARD_DEVICE_RHPORT_SPEED   OPT_MODE_FULL_SPEED
  #endif
#endif

// Device mode with rhport and speed defined by board.mk
#if   BOARD_DEVICE_RHPORT_NUM == 0
  #define CFG_TUSB_RHPORT0_MODE     (OPT_MODE_DEVICE | BOARD_DEVICE_RHPORT_SPEED)
#elif BOARD_DEVICE_RHPORT_NUM == 1
  #define CFG_TUSB_RHPORT1_MODE     (OPT_MODE_DEVICE | BOARD_DEVICE_RHPORT_SPEED)
#else
  #error "Incorrect RHPort configuration"
#endif

#ifndef CFG_TUSB_OS
#define CFG_TUSB_OS               OPT_OS_NONE
#endif

// CFG_TUSB_DEBUG is defined by compiler in DEBUG build
// #define CFG_TUSB_DEBUG           0

/* USB DMA on some MCUs can only access a specific SRAM region with restriction on alignment.
 * Tinyusb use follows macros to declare transferring memory so that they can be put
 * into those specific section.
 * e.g
 * - CFG_TUSB_MEM SECTION : __attribute__ (( section(".usb_ram") ))
 * - CFG_TUSB_MEM_ALIGN   : __attribute__ ((aligned(4)))
 */
#ifndef CFG_TUSB_MEM_SECTION
#define CFG_TUSB_MEM_SECTION
#endif

#ifndef CFG_TUSB_MEM_ALIGN
#define CFG_TUSB_MEM_ALIGN          __attribute__ ((aligned(4)))
#endif

// #define CFG_TUD_ENABLED       1

// // Default is max speed that hardware controller could support with on-chip PHY
//#define CFG_TUD_MAX_SPEED     BOARD_TUD_MAX_SPEED

//--------------------------------------------------------------------
// DEVICE CONFIGURATION
//--------------------------------------------------------------------

#ifndef CFG_TUD_ENDPOINT0_SIZE
#define CFG_TUD_ENDPOINT0_SIZE    64
#endif

//------------- CLASS -------------//
#define CFG_TUD_CDC               1
#define CFG_TUD_MSC               0
#define CFG_TUD_HID               0
#define CFG_TUD_MIDI              1
#define CFG_TUD_VENDOR            0

// MIDI FIFO size of TX and RX
#define CFG_TUD_MIDI_RX_BUFSIZE   (TUD_OPT_HIGH_SPEED ? 512 : 64)
#define CFG_TUD_MIDI_TX_BUFSIZE   (TUD_OPT_HIGH_SPEED ? 512 : 64)

#define CFG_TUD_CDC_RX_BUFSIZE   (TUD_OPT_HIGH_SPEED ? 512 : 64)
#define CFG_TUD_CDC_TX_BUFSIZE   (TUD_OPT_HIGH_SPEED ? 512 : 64)
// CDC Endpoint transfer buffer size, more is faster
#define CFG_TUD_CDC_EP_BUFSIZE   (TUD_OPT_HIGH_SPEED ? 512 : 64)

#ifdef __cplusplus
 }
#endif

#endif /* _TUSB_CONFIG_H_ */

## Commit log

2022-12-14 keypad handling works and lights up correct LED
    [main.cpp]
2022-12-15 Handle WS2812 LED
2022-12-19 change velocity by turning while pressing it and holding down a key
2022-12-26 Can record + start adding hardware
    [bottom.stl, knob.stl, output.scad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]
2022-12-28 first prototype board
    [seeq-B_Cu.gbr, seeq-B_Mask.gbr, seeq-B_Paste.gbr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]
2022-12-29 Add 3D models
    [seeq.kicad_pcb, seeq.step, seeq.stl]
2023-01-25 Update software for PCB + PCB fixes
    [seeq.kicad_pcb, seeq.kicad_sch]
2023-02-16 Add kibot and docs
    [seeq.kicad_pcb, seeq.kicad_sch]
2023-02-16 fix erc / drc
    [seeq.kicad_pcb, seeq.kicad_sch]
2023-02-16 try to add 3D fo switches
    [SW_Cherry_MX_PCB.stp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]
2023-02-16 stp files
    [seeq.kicad_pcb]
2023-03-25 Add download links.
    [seeq.kicad_pcb]
2023-03-25 Add jlc order number
    [seeq.kicad_pcb]
